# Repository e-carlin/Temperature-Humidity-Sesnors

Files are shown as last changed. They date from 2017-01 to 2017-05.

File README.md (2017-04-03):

# Wireless Temperature and Humidity Sensors
Senior project for The University of Puget Sound Capstone in C.S. (CS440).  
This project consists of building wireless temperature and humidity sensors for the museum cases at the [Lelosska Foundation](http://lelooska.org/). 

Parts:
- Nodes: 
	- Moteino R4 (RFM69 915Mhz)
- Sensors: 
	- DHT22
- Gateway:
	- Moteino R4 USB (RFM69 915Mhz)
	- Raspberry Pi
- Data visualization:
	- Ruby on Rails website
	- SQLite database
	- Hosted on AWS EC2

## Battery powered sensor
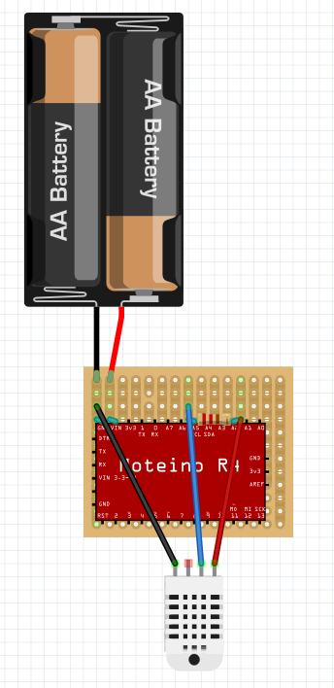
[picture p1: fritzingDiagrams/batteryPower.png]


## All of the Moteinos  
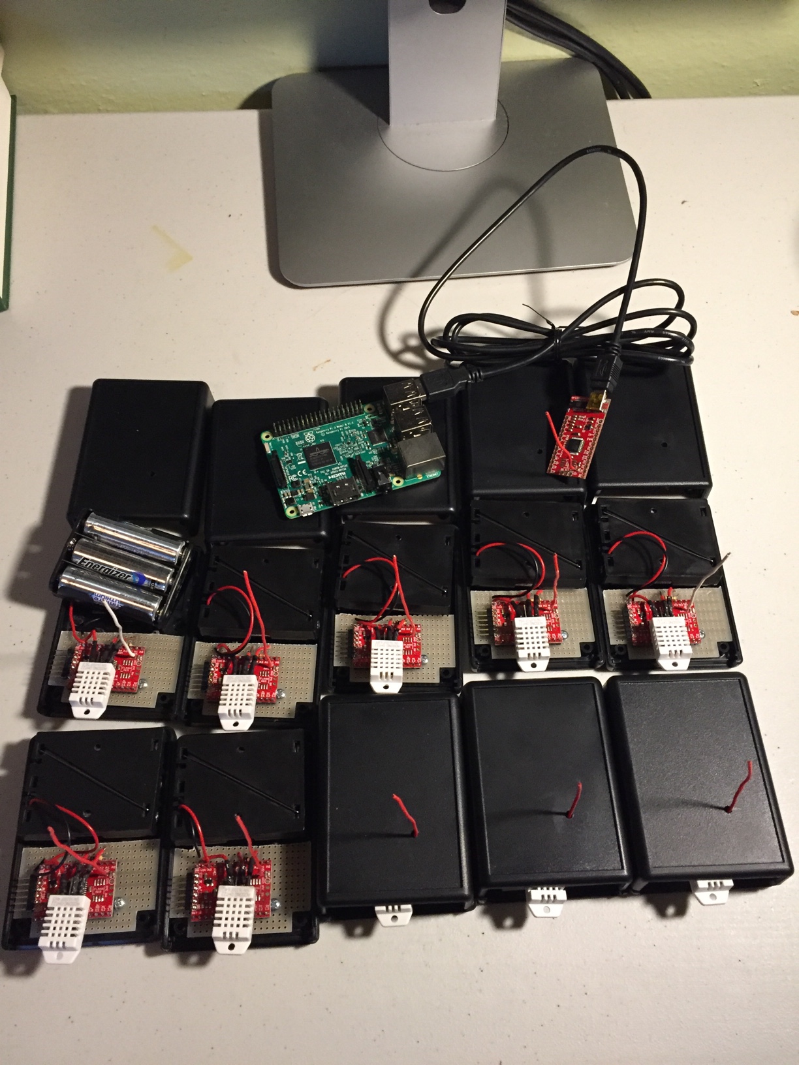
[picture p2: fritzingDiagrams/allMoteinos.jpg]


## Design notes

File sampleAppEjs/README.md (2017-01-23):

Here is a sample web app using Node.js and Express.js

To start the app do:
1) $ cd sampleWebApp
2) $ npm install
3) $ npm start

Navigate to localhost:3000 to see the welcome page
Navigate to localhost:3000/users to see a list of all users in the database
You can add users by opening up the sqlite interactive console and inserting
them. Refresh the page and you will see the additions!

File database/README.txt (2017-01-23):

=================
About the Schema
=================

------
|User|
------
Straightforward, users who can see the website.

------
|Admin|
------
These are users with the ability to manage other users.

	* Add new users.
	* Delete old users.
	* Grant admin priveleges of pre-exisitng users.

------------
|MuseumCase|
------------
These are the exhibit cases. Serves as a reference point.

--------
|Sensor|
--------
The Moteino sensors. I don't know how they transmit data, but I figured for information to store, we'd want these two values.

	* id: The unique identifier for the sensor.
	* batteryLife: Lets us know if a battery needs to be replaced soon

----------
|Contains|
----------
Shows which cases contain which sensors. Useful for data vizualization and if we need multiple sensors to a case.

------
|Data|
------
The data the Moteino's transmit.

	* id: Which sensor sent the data
	* timeStamp: YYYY/MM/DD - HH/MM (The time of transmission)
	* temperature: Temperature, probably Farenheit
	* humidity: Humidity in percentage

This at least covers the minimum desired information

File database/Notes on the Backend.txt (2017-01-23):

==Selecting the Database==
We were considering between MySQL and SQLite. MySQL is oftentimes quoted in the industry, so it seemed like a good idea. However, on further investigation we realized that MySQL would be far too complex for such a small database that we would need. 

==Making the Schema==
Super simple, given that the only data needed was user info, sensor layout, and data transmission. 

==Connecting with the web framework==
We had to determine how to the SQLite DB via Javascript. We found an npm module that works just fine.

==Working in Parallel==
With the schema done, and things more or less determined for integrating it with our other stuff, that's one less thing to worry about.

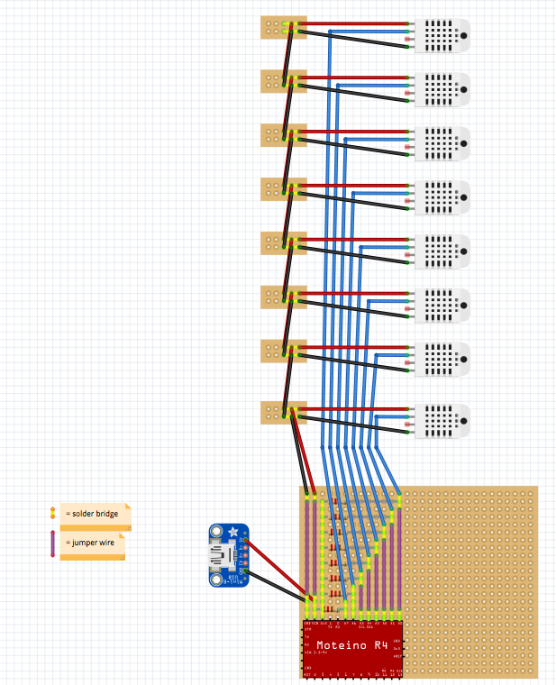
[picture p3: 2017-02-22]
fritzingDiagrams/wiredProtoBoard.png

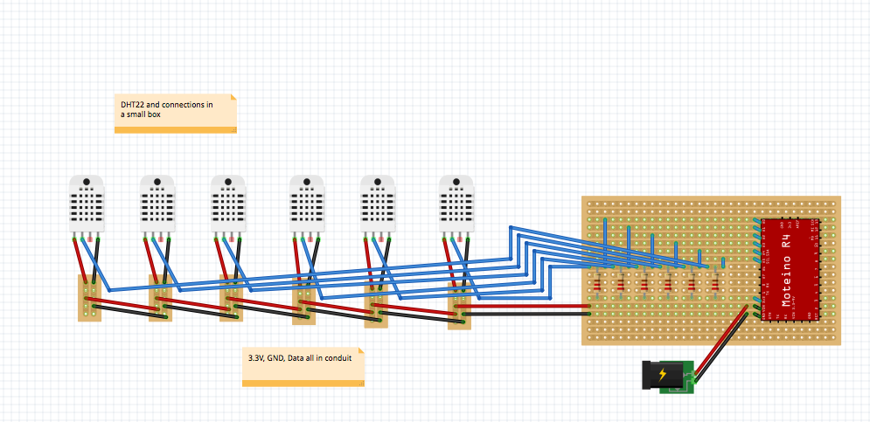
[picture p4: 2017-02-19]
fritzingDiagrams/wiredPower.png

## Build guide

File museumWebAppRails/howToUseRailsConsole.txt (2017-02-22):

The rails console is a super easy way to create records (objects that will be stored in the db i.e a reading, node,...) and manipulate them. Likewise, it is a simple ruby interpreter. For example if you have read that to append to a file in Ruby you do File.open("output.txt","a+") { |f| f.puts("some text") }. Then you can test this out in the console.  

I use the console mostly for debugging purposes. It can be really hard to see where exactly something went wrong when your clicking around on the site and the console creates and easy way to try things line by line and see what works.

For an example usage I figured I'd just run through the testing I did when I implemented foreign keys. 

1) Start the console (*note: you can just type rails c for short)
	$ rails console

2) Get all nodes currently in the database
	$ Node.all

3) Create a new node object and reference it as n
	$ n = Node.new

4) See what n currently looks like
	$ n

5) Try to save n
	$ n.save
	You'll see that a "not null constraint failed: nodes.network_id"

6) So set the network id
	$ n.network_id = 5 

6) Look at n again to make sure the network_id is what you think it is
	$ n

7) Now save it
	$ n.save

8) Create a sensor object and reference it as s
	$ s = Sensor.new

9) Set s pin 
	$ s.pin = 5

8) Set its network_id to a non-existent network_id
	$ s.network_id = 666

9) Try to save it
	$ s.save
	Printed on the screen is the SQL query that was run and you'll see that it tried to find a node with network_id = 666. This doesn't exist in our database so we can't create a sensor referencing it. The foreign key worked!

10) Add the proper network_id
	$ s.network_id = n.network_id
	Note: You could also say s.network_id = 5 (or any other valid network_id currently in our db)

11) Save s
	$ s.save

12) See the sensor
	$ Sensor.all

Thats a basic interaction with the console and one that I used to check if our foreign keys were working. 

The nodes and sensors you added exists in the db. So, if you were to create a new reading, save it, and then in your web browser navigate to /readings you will see the reading you just created.

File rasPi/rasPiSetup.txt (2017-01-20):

1) Download latest version of Raspbian 

https://www.raspberrypi.org/downloads/raspbian/

2) Follow instructions for you machine

https://www.raspberrypi.org/documentation/installation/installing-images/README.md

3) Add wifi provision service (this service allows us to provision the Pi on a new
network without needing to connect a display,mouse,or keyboard to it)

https://github.com/sabhiram/raspberry-wifi-conf#why

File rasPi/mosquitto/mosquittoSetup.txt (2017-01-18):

Setting up Mosquito MQTT broker:

Debian:
	1) Update and install dependecies

	$ apt-get update
	$ apt-get install build-essential libwrap0-dev libssl-dev libc-ares-dev uuid-dev xsltproc

	2) Add the mosquitto repo

	$ sudo apt-add-repository ppa:mosquitto-dev/mosquitto-ppa
	$ sudo apt-get update

	3) Install mosquitto broker

	$ sudo apt-get install mosquitto

	4) Install developer libs

	$ sudo apt-get install libmosquitto-dev

	5) Install client packages

	$ sudo apt-get install mosquitto-clients

	6) Ensure broker is running

	$ sudo service mosquitto status

OS X:
	1) Install via homebrew

	$ brew install mosquitto

Testing:

1) Start the service

$ /usr/local/sbin/mosquitto -c /usr/local/etc/mosquitto/mosquitto.conf

2) Subscribe to to "mqtt" topic

$ mosquitto_sub -h localhost -t "mqtt" -v

3) In a new terminal window publish to that topic

$ mosquitto_pub -h localhost -t "mqtt" -m "Hello MQTT"

4) Another option is to run the python "mqttSubscriber.py" and "mqttPublisher.py" scripts

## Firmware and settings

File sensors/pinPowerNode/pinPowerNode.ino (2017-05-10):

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
// Licence can be viewed at
// http://www.gnu.org/licenses/gpl-3.0.txt
//
// Please maintain this license information along with authorship
// and copyright notices in any redistribution of this code
// ********************************************************************************** 
#include <RFM69.h>         //get it here: https://www.github.com/lowpowerlab/rfm69
#include <RFM69_ATC.h>     //get it here: https://www.github.com/lowpowerlab/rfm69
#include <DHT.h>
#include <LowPower.h> //get library from: https://github.com/lowpowerlab/lowpower
                      //writeup here: http://www.rocketscream.com/blog/2011/07/04/lightweight-low-power-arduino-library/
//***** USB port BAUD *****
//#define SERIAL_BAUD 9600 //Just for testing. 9600 seems to work, not really sure what it actually means

//******* LED **************
#define LED 9 // Moteinos have LEDs on D9

//***** RFM69 definitions ********************************

//================= THIS NUMBER MUST BE UNIQUE FOR EACH SENSOR ==================
#define NODEID        9    //must be unique for each node on same network (range up to 254, 255 is used for broadcast)
//=====================================================================

#define NETWORKID     100  //Don't change this. The same on all nodes that talk to each other (range up to 255)
#define GATEWAYID     1 //Don't change this. Same for all nodes in the network
#define FREQUENCY     RF69_915MHZ
#define ENCRYPTKEY    "sampleEncryptKey" //exactly the same 16 characters/bytes on all nodes!
#define MAX_PACKET_SIZE 61 //The maximum number of bytes in a packet
//Auto Transmission Control - dials down transmit power to save battery
//Usually you do not need to always transmit at max output power
//By reducing TX power even a little you save a significanadt amount of battery power
//This setting enables this gateway to work with remote nodes that have ATC enabled to
//dial their power down to only the required level (ATC_RSSI)
#define ENABLE_ATC    //comment out this line to disable AUTO TRANSMISSION CONTROL
#define ATC_RSSI      -80
RFM69_ATC radio;

//********** DHT22 definitions ************************
#define DHTTYPE DHT22
int SENSOR_PIN = 19; //Digital 19 => A5 on moteino
int POWER_PIN = 16; //Digital 16 => A2 on moteino
DHT dht(SENSOR_PIN, DHTTYPE);

//******** LowPower definitions ***********************************
#include <avr/wdt.h>
#define Reset_AVR() wdt_enable(WDTO_15MS); while(1) {} //This resets the chip
//Sleep timing
long randSleepOffset;
//Each value is multiplied by 8 because the lowpower sleep timer can only sleep for a maximum of 8 sec.
#define MIN_SLEEP 90 //MIN_SLEEP_TIME * 8 = minimum number of seconds between transmissions
#define MAX_SLEEP_OFFSET 15 // MAX_SLEEP_OFFSET * 8 = maximum number of seconds to add to MIN_SLEEP_TIME
// (MIN_SLEEP * 8) <= sleepTime <= (MIN_SLEEP_TIME * 8) + (MAX_SLEEP_OFFSET * 8)

/*
* Initializes radio and DHT22
*/                                                     //Used in cases where a reading was NAN
void setup() {
  //Seed random number generator 
  //Analog 0 is unconnected so the noise on it will give a good random seed
 randomSeed(analogRead(0));
  
  //Initialize the radio
  radio.initialize(FREQUENCY, NODEID, NETWORKID);
  radio.encrypt(ENCRYPTKEY);

  // Initialize sensor
  dht.begin();

  //Auto Transmission Control - dials down transmit power to save battery (-100 is the noise floor, -90 is still pretty good)
  //For indoor nodes that are pretty static and at pretty stable temperatures (like a MotionMote) -90dBm is quite safe
  //For more variable nodes that can expect to move or experience larger temp drifts a lower margin like -70 to -80 would probably be better
  //Always test your ATC mote in the edge cases in your own environment to ensure ATC will perform as you expect
  radio.enableAutoPower(ATC_RSSI);
}

/*
* Blinks the LED on pin for DELAY_MS miliseconds
*/
void Blink(byte PIN, int DELAY_MS)
{
  pinMode(PIN, OUTPUT);
  digitalWrite(PIN, HIGH);
  delay(DELAY_MS);
  digitalWrite(PIN, LOW);
}

/*
* Retrieves the voltage in millivolts, doesn't require additional hardware
*/
long readVcc() {
  // Read 1.1V reference against AVcc
  // set the reference to Vcc and the measurement to the internal 1.1V reference
  ADMUX = _BV(REFS0) | _BV(MUX3) | _BV(MUX2) | _BV(MUX1);

  delay(2); // Wait for Vref to settle
  ADCSRA |= _BV(ADSC); // Start conversion
  while (bit_is_set(ADCSRA, ADSC)); // measuring

  uint8_t low  = ADCL; // must read ADCL first - it then locks ADCH
  uint8_t high = ADCH; // unlocks both

  long result = (high << 8) | low;

  result = 1125300L / result; // Calculate Vcc (in mV); 1125300 = 1.1*1023*1000
  return result; // Vcc in millivolts
}

/*
* The device loops through this taking a reading, transmitting, sleeping, then repeat...
*/
void loop() {
  char payload[MAX_PACKET_SIZE]; //Packet we will place readings in and send
    char tempFaren[6]; //
  char humidity[6];

  //Turn on power to the pin and let it stabilize before reading
  pinMode(POWER_PIN, OUTPUT);
  digitalWrite(POWER_PIN, HIGH);
  delay(800);
   
  //Take the readings    
  float h = dht.readHumidity();
  float t = dht.readTemperature(true);  //true => temp. in farenheit
  long v = readVcc();
  
  //Turn off power to the DHT22
  digitalWrite(POWER_PIN, LOW);
  
  //If failed to read sensor or voltage then send notice and reset
  if (isnan(h)|| isnan(t) || isnan(v)) {
    Blink (LED, 1000); //Let someone watching now there was a problem
    sprintf(payload, "{ \"error\" : \"A reading was NAN\","); //Copy values to the packet

    //Try sending the packet
    // If no ACK is received try once more
    if(!radio.sendWithRetry(GATEWAYID, payload, strlen(payload))){
      radio.send(GATEWAYID, payload, strlen(payload)); //No ACK so try again
    }

    //Reset the device
    Reset_AVR();
  }

  /* The reading was successful. Build the packet and send! */

  //This is necessary for copying floats to a char[]
  //4 is mininum width, 2 is precision
  dtostrf(t, 4, 2, tempFaren);
  dtostrf(h, 4, 2, humidity);

  //Build packet
  sprintf(payload, "{\"temp\" : %s, \"hum\" : %s, \"volt\" : %d, ", tempFaren, humidity, v);
  
    //Try sending the packet
    // If no ACK is received try once more
    if(!radio.sendWithRetry(GATEWAYID, payload, strlen(payload))){
      radio.send(GATEWAYID, payload, strlen(payload)); //No ACK so try again
    }

  //A little flash to show we transmitted
  Blink(LED, 3);

  //Power down
  radio.sleep();
  randSleepOffset = random(MAX_SLEEP_OFFSET);
  //Need to loop becasue max sleep for powerDown is only 8s
  for(int i=0; i<MIN_SLEEP + randSleepOffset; i++){
    LowPower.powerDown(SLEEP_8S, ADC_OFF, BOD_OFF);
}
}

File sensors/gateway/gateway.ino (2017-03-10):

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
// Licence can be viewed at                               
// http://www.gnu.org/licenses/gpl-3.0.txt
//
// Please maintain this license information along with authorship
// and copyright notices in any redistribution of this code
// **********************************************************************************
#include <RFM69.h>         //get it here: https://www.github.com/lowpowerlab/rfm69
#include <RFM69_ATC.h>     //get it here: https://www.github.com/lowpowerlab/rfm69

//*********************************************************************************************
//************ IMPORTANT SETTINGS - YOU MUST CHANGE/CONFIGURE TO FIT YOUR HARDWARE *************
//*********************************************************************************************
#define NODEID        1    //unique for each node on same network
#define NETWORKID     100  //the same on all nodes that talk to each other
//Match frequency to the hardware version of the radio on your Moteino (uncomment one):

#define FREQUENCY     RF69_915MHZ
#define ENCRYPTKEY    "sampleEncryptKey" //exactly the same 16 characters/bytes on all nodes!
//*********************************************************************************************
//Auto Transmission Control - dials down transmit power to save battery
//Usually you do not need to always transmit at max output power
//By reducing TX power even a little you save a significant amount of battery power
//This setting enables this gateway to work with remote nodes that have ATC enabled to
//dial their power down to only the required level
#define ENABLE_ATC    //comment out this line to disable AUTO TRANSMISSION CONTROL
//*********************************************************************************************
// e-carlin: I think ours should be 9600
// #define SERIAL_BAUD   115200
#define SERIAL_BAUD 9600


#define LED  9 // Moteinos have LEDs on D9


#ifdef ENABLE_ATC
  RFM69_ATC radio;
#else
  RFM69 radio;
#endif


void setup() {
  Serial.begin(SERIAL_BAUD);
  delay(10);
  radio.initialize(FREQUENCY,NODEID,NETWORKID);
  radio.encrypt(ENCRYPTKEY);
  //radio.setFrequency(919000000); //set frequency to some custom frequency
}

byte ackCount=0;
uint32_t packetCount = 0;
void loop() {
  if (radio.receiveDone())
  {
    for (byte i = 0; i < radio.DATALEN; i++){
      Serial.print((char)radio.DATA[i]);
    }
    //Attach the node_id to the sender to the packet
    Serial.print(" \"node_id\" : "); 
    Serial.print(radio.SENDERID);
    Serial.print(",");
    
    if (radio.ACKRequested())
    {
      byte theNodeID = radio.SENDERID;
      radio.sendACK();
    }
    Serial.println();
    Blink(LED,3);
  }
}

void Blink(byte PIN, int DELAY_MS)
{
  pinMode(PIN, OUTPUT);
  digitalWrite(PIN,HIGH);
  delay(DELAY_MS);
  digitalWrite(PIN,LOW);
}

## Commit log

2017-01-23 A sample web app hooked to SQLite
2017-01-23 Switched to ejs
2017-01-23 Initial rails app
2017-01-30 Rails generate
2017-02-07 Fixed python imports and appending of timestamp
    [node.ino, readFromSerial.py]
2017-02-14 Added reset on NAN
    [node.ino, readFromSerial.py]
2017-02-14 Setup raspi node battery test
2017-02-15 Fixed by adding json type header
    [readFromSerial.py]
2017-02-15 Permit volt and sId
2017-02-15 pseudocode for adding nodes and sensors to db
2017-02-15 Properly formatted error json
    [node.ino]
2017-02-15 Added render json with error messages
    [readFromSerial.py]
2017-02-19 Added fritz diagram
    [wiredPower.fzz]
2017-02-19 Added .fzz and updated diagram
    [wiredPower.fzz]
2017-02-19 added multiple sensor line break
2017-02-19 moved reset to after checking all sensors
    [node.ino, readFromSerial.py]
2017-02-19 Added another sensor
2017-02-20 Restructure directories
    [batteryPower.fzz]
2017-02-20 Added info about errors
    [readFromSerial.py]
2017-02-21 Added node and sensor and setup foreign keys
2017-02-22 added rails console howto
    [batteryPower.fzz]
2017-02-22 Fritzing using protoboard
    [wiredPower.fzz, wiredPowerProtoBoard.fzz]
2017-02-26 Added adding new nodes and sensors
2017-02-28 Updated fritzing pics and created new folder for mote with single DHT22
    [batteryPower.fzz]
2017-03-01 Removed testing print
2017-03-01 ADding more to error logging
    [readFromSerial.py]
2017-03-02 Fixing formating of POST
    [readFromSerial.py]
2017-03-02 added pin power node and commented out post for now
2017-03-06 Fixed and commented pinPowerNode
    [wiredPower.fzz]
2017-03-06 Removed sending sensor pin for nodes with only one sensor
2017-03-06 Removed pin
2017-03-06 Removed pin from seed
2017-03-07 Fixed node_id vs nodeID
    [readFromSerial.py]
2017-03-07 Added sensor name to schema
2017-03-08 Added last_reading and voltage to nodes
2017-03-08 fixing secret key error
    [readFromSerial.py]
2017-03-08 Fixed pin power down
    [gateway.ino, pinPowerNode.ino]
2017-03-10 Landing page tweaks
2017-03-21 Added more print outs
2017-03-22 Removed sensor from readings controller
2017-03-25 Added Moteino device path symlink
2017-03-27 Added forgot password button and removed admin forgot column
2017-03-28 Fixed str error in script and added random sleeping
    [pinPowerNode.ino, readFromSerial.py]
2017-03-29 updated wiring diagrams
    [batteryPower.fzz]
2017-03-29 Removed wired power from README
2017-04-06 Removed login button
2017-04-06 adde /sensors to url
2017-04-08 Changed node order to be ordered on sensor num
2017-04-11 Switch from Date to Time
2017-04-18 added /sensors assets prefix
2017-04-18 Switch to web url
2017-05-10 Fixed pin typo

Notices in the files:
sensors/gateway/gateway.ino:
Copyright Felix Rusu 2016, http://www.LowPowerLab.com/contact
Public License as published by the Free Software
